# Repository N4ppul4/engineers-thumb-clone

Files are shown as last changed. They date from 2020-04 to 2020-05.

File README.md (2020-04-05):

# engineers-thumb-clone
Compression guitar pedal clone

Just my take on the popular compression pedal, its designed to use with perfboard.
This is not in any means verified or anything so take it with a grain of salt.
Program used for schematics and pcb layout is KiCad

Dont know much about copyrights so I assume its same as original design

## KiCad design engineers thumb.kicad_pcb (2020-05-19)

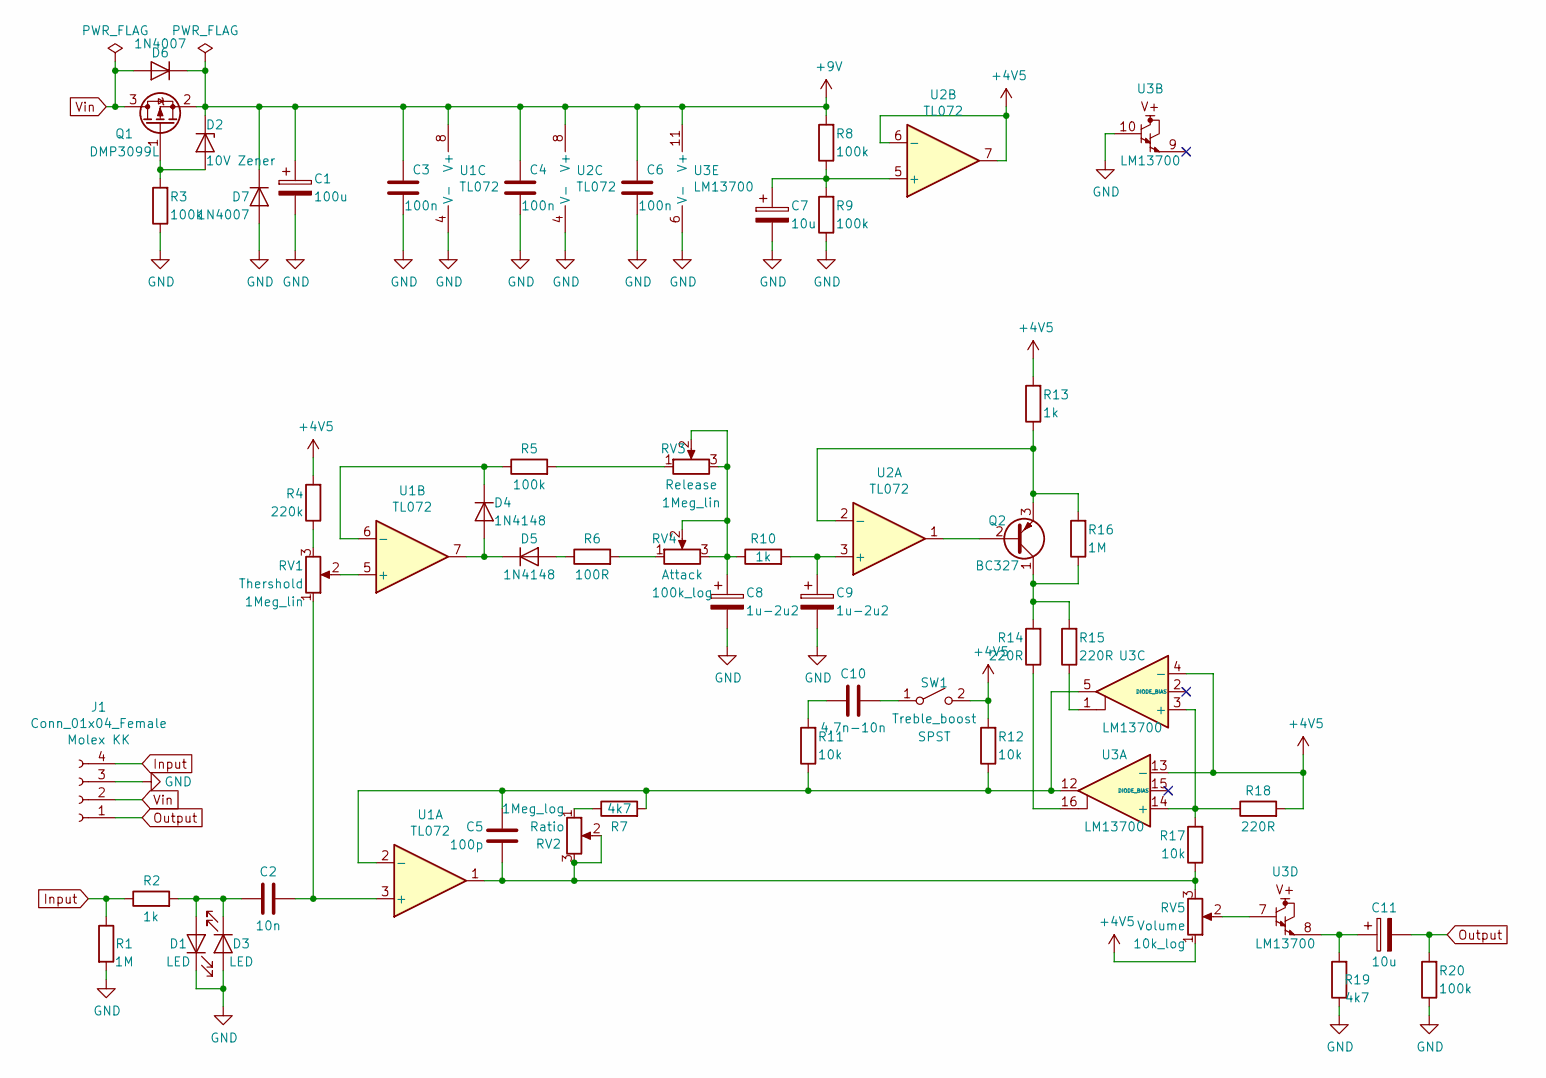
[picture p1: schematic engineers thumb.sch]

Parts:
C1: 100u; CP_Radial_D6.3mm_P2.50mm
C2: 10n; C_Box_P5.08mm
C3, C4, C6: 100n; C_Box_P5.08mm
C5: 100p; C_Disc_P2.50mm
C7, C11: 10u; CP_Radial_D6.3mm_P2.50mm
C8, C9: 1u-2u2; CP_Radial_D6.3mm_P2.50mm
C10: 4.7n-10n; C_Box_P5.08mm
D1, D3: LED; LED_D3.0mm
D2: 10V Zener; D_DO-35_SOD27_P7.62mm_Horizontal
D4, D5: 1N4148; D_DO-35_SOD27_P7.62mm_Horizontal
D6, D7: 1N4007; D_DO-35_SOD27_P7.62mm_Horizontal
J1: Conn_01x04_Female; Molex_KK-254_01x04_P2.54mm_Right_Angle
Q1: DMP3099L; SOT-23W_Handsoldering
Q2: BC327; TO-92_Inline_Wide
R1, R16: 1M; R_Axial_DIN0204_L3.6mm_D1.6mm_P7.62mm_Horizontal
R2, R10, R13: 1k; R_Axial_DIN0204_L3.6mm_D1.6mm_P7.62mm_Horizontal
R3, R5, R8, R9, R20: 100k; R_Axial_DIN0204_L3.6mm_D1.6mm_P7.62mm_Horizontal
R4: 220k; R_Axial_DIN0204_L3.6mm_D1.6mm_P7.62mm_Horizontal
R6: 100R; R_Axial_DIN0204_L3.6mm_D1.6mm_P7.62mm_Horizontal
R7, R19: 4k7; R_Axial_DIN0204_L3.6mm_D1.6mm_P7.62mm_Horizontal
R11, R12, R17: 10k; R_Axial_DIN0204_L3.6mm_D1.6mm_P7.62mm_Horizontal
R14, R15, R18: 220R; R_Axial_DIN0204_L3.6mm_D1.6mm_P7.62mm_Horizontal
RV1, RV3: 1Meg_lin; Alpha_16mm_potentiometer
RV2: 1Meg_log; Alpha_16mm_potentiometer
RV4: 100k_log; Alpha_16mm_potentiometer
RV5: 10k_log; Alpha_16mm_potentiometer
SW1: SPST; PinSocket_2x01_P2.54mm_Vertical_Wide
U1, U2: TL072; DIP-8_Socket
U3: LM13700; DIP-16_Socket

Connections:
+4V5: R4.2, R12.2, R13.2, R18.2, RV5.1, SW1.2 (B), U2.6 (-), U2.7, U3.4 (-), U3.13 (-)
+9V: C1.1, C3.1, C4.1, C6.1, D2.1 (K), D6.1 (K), D7.1 (K), Q1.2 (S), R8.2, U1.8 (V+), U2.8 (V+), U3.11 (V+)
GND: C1.2, C3.2, C4.2, C6.2, C7.2, C8.2, C9.2, D1.1 (K), D3.2 (A), D7.2 (A), J1.3, R1.2, R3.1, R9.1, R19.1, R20.1, U1.4 (V-), U2.4 (V-), U3.6 (V-), U3.10
Input: J1.4, R1.1, R2.1
unnamed: C2.1, RV1.1, U1.3 (+)
unnamed: C2.2, D1.2 (A), D3.1 (K), R2.2
unnamed: C5.1, R7.2, R11.1, R12.1, U1.2 (-), U3.5, U3.12
unnamed: C5.2, R17.1, RV2.2, RV2.3, RV5.3, U1.1
unnamed: C7.1, R8.1, R9.2, U2.5 (+)
unnamed: C8.1, R10.1, RV3.2, RV3.3, RV4.2, RV4.3
unnamed: C9.1, R10.2, U2.3 (+)
unnamed: C10.1, SW1.1 (A)
unnamed: C10.2, R11.2
unnamed: C11.1, R19.2, U3.8
unnamed: D2.2 (A), Q1.1 (G), R3.2
unnamed: D4.1 (K), R5.1, U1.6 (-)
unnamed: D4.2 (A), D5.1 (K), U1.7
unnamed: D5.2 (A), R6.1
unnamed: Q2.1 (C), R14.2, R15.2, R16.1
unnamed: Q2.2 (B), U2.1
unnamed: Q2.3 (E), R13.1, R16.2, U2.2 (-)
unnamed: R4.1, RV1.3
unnamed: R5.2, RV3.1
unnamed: R6.2, RV4.1
unnamed: R7.1, RV2.1
unnamed: R14.1, U3.16
unnamed: R15.1, U3.1
unnamed: R17.2, R18.1, U3.3 (+), U3.14 (+)
unnamed: RV1.2, U1.5 (+)
unnamed: RV5.2, U3.7
Output: C11.2, J1.1, R20.2
Vin: D6.2 (A), J1.2, Q1.3 (D)

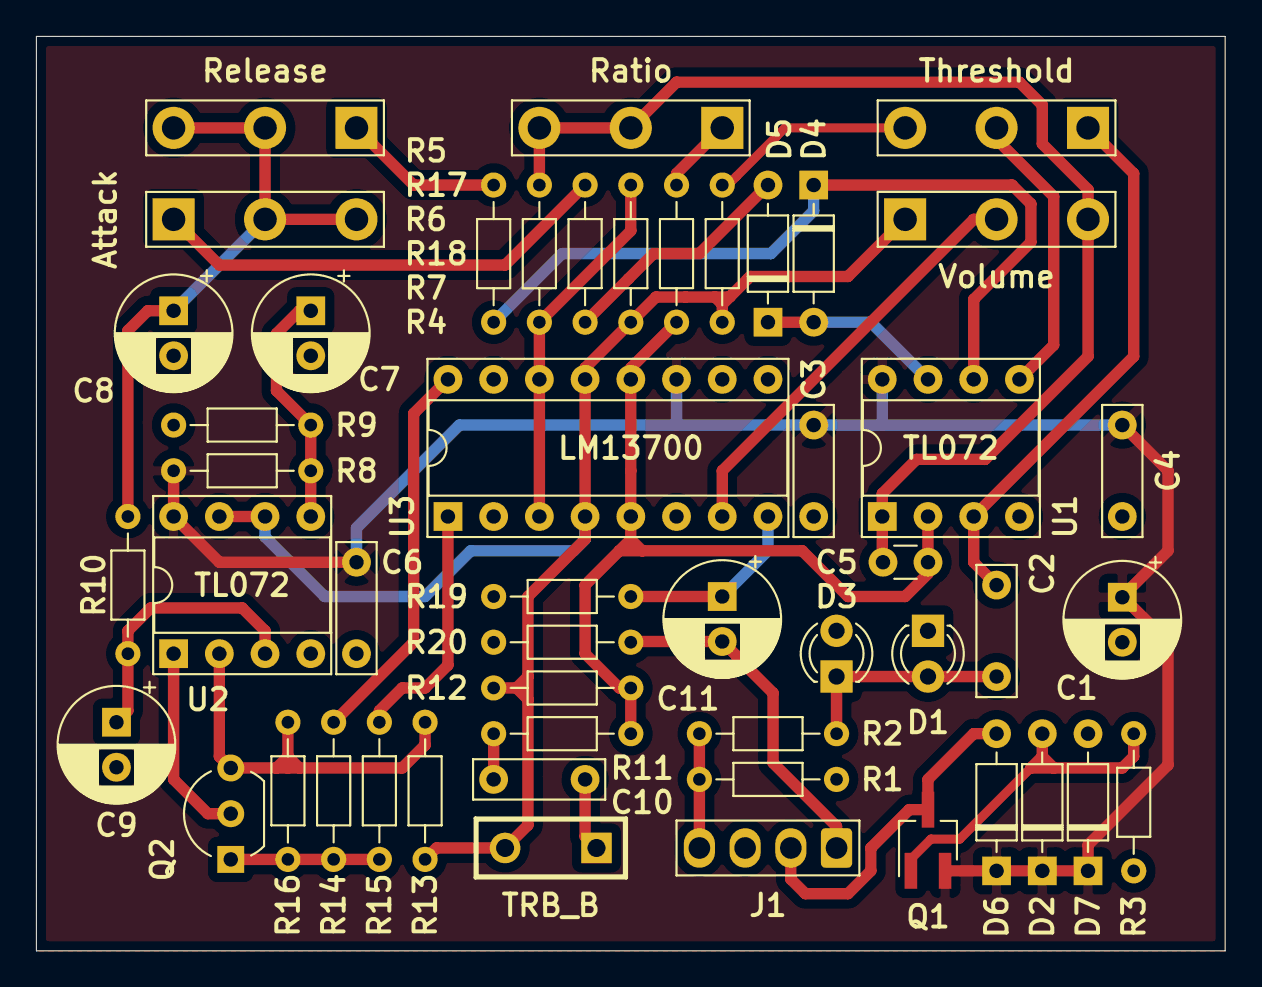
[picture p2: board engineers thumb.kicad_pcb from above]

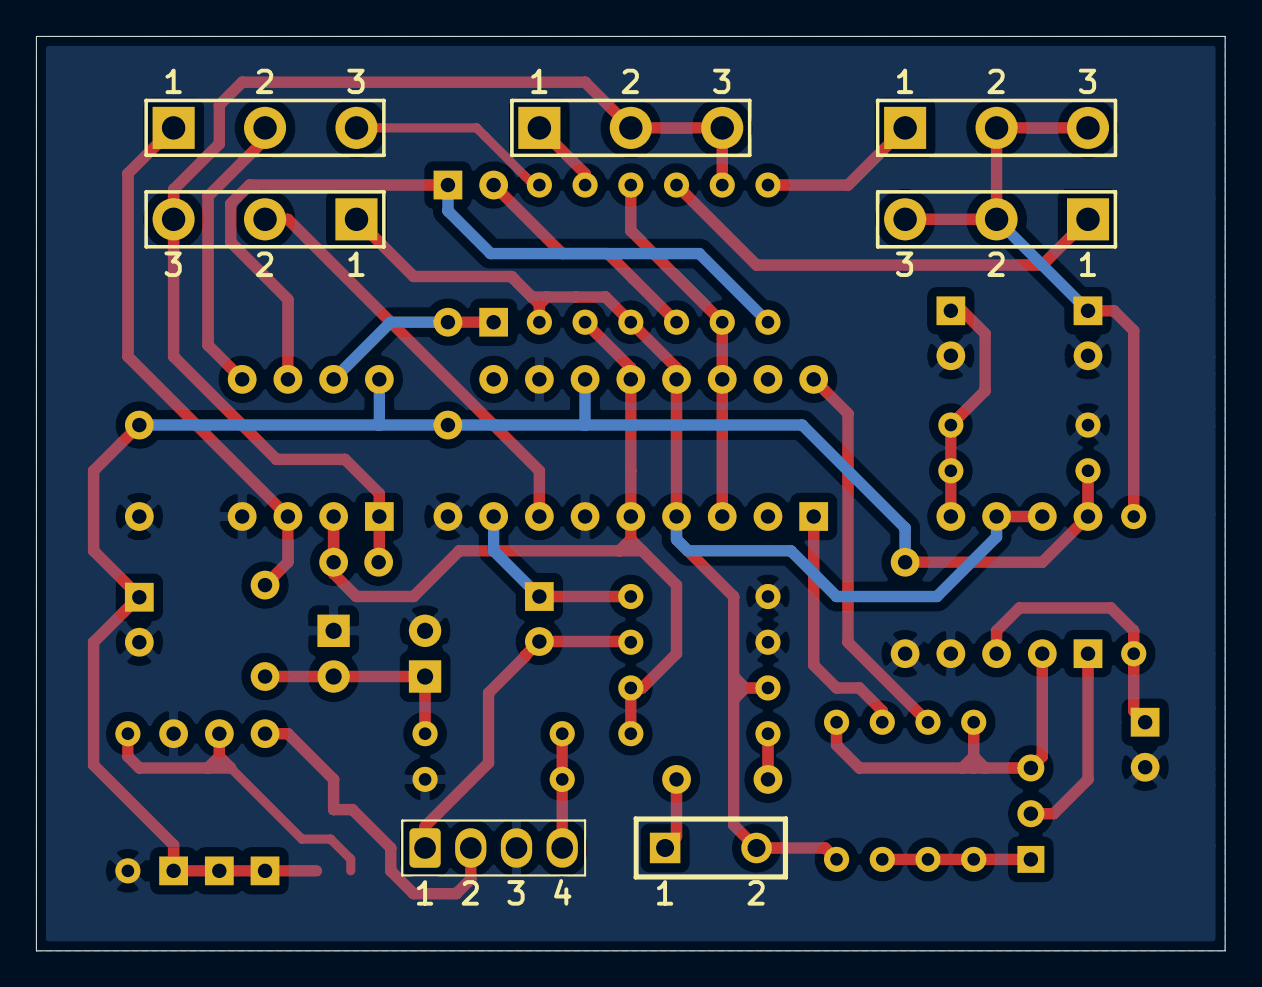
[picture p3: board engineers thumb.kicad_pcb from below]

Board: 2 copper layers, 66.0 x 50.8 mm, 50 parts (6 on the bottom side), 32 nets.

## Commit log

2020-03-11 Corrected footprints
    [engineers thumb.kicad_pcb, engineers thumb.sch]
2020-03-18 updated layout
    [engineers thumb.kicad_pcb, engineers thumb.sch]
2020-04-05 added capacitor
    [engineers thumb.kicad_pcb, engineers thumb.sch]
2020-04-22 Starting to do changes
    [engineers thumb.kicad_pcb, engineers thumb.sch]
2020-04-24 Almost done
    [engineers thumb.kicad_pcb, engineers thumb.sch]
2020-04-28 Its never done
    [engineers thumb.kicad_pcb, engineers thumb.sch]
2020-05-19 Good progress made
    [engineers thumb.kicad_pcb, engineers thumb.sch]
